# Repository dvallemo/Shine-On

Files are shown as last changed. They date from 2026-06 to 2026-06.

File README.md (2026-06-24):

# Shine On V1

A simple 2-layer LED indicator board designed to plug into a Raspberry Pi 4 GPIO header. Built as a hands-on exercise in schematic capture, PCB layout, component selection, DFM, and hand soldering.

**Designed in:** KiCad  
**Fabricated by:** OSHPark ($5.00 for 3 boards)  
**Components sourced from:** DigiKey  
**Assembly:** Hand soldered by designer  
**Board size:** 25.4 x 25.4 mm (1.00 x 1.00 in), 2-layer

---

## Schematic

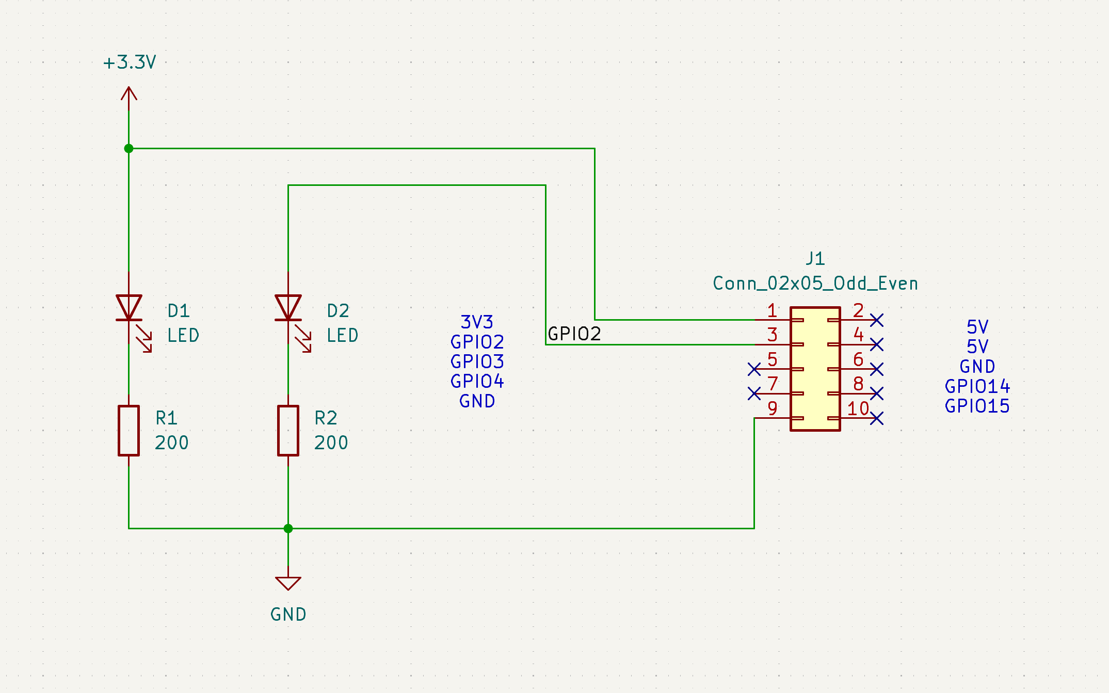
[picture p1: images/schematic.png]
Schematic


Both LEDs are driven in a simple series configuration:

- **D1:** +3.3V -> D1 (LED 1206) -> R1 (200 ohm) -> GND
- **D2:** GPIO2 -> D2 (LED 1206) -> R2 (200 ohm) -> GND

Current limiting resistors R1 and R2 are 200 ohm, 1/4 W rated, 1206 package. At 3.3V with a typical LED forward voltage of ~2.0V:

> I = (3.3V - 2.0V) / 200 ohm = ~6.5 mA

Well within GPIO drive capability (~16 mA max) and LED ratings. Power dissipation per resistor ~8.5 mW, well under the 250 mW rating.

The 10-pin dual-row header (J1) connects directly to the Raspberry Pi 4 GPIO header, exposing +3.3V, GPIO2, and GND.

---

## PCB Layout

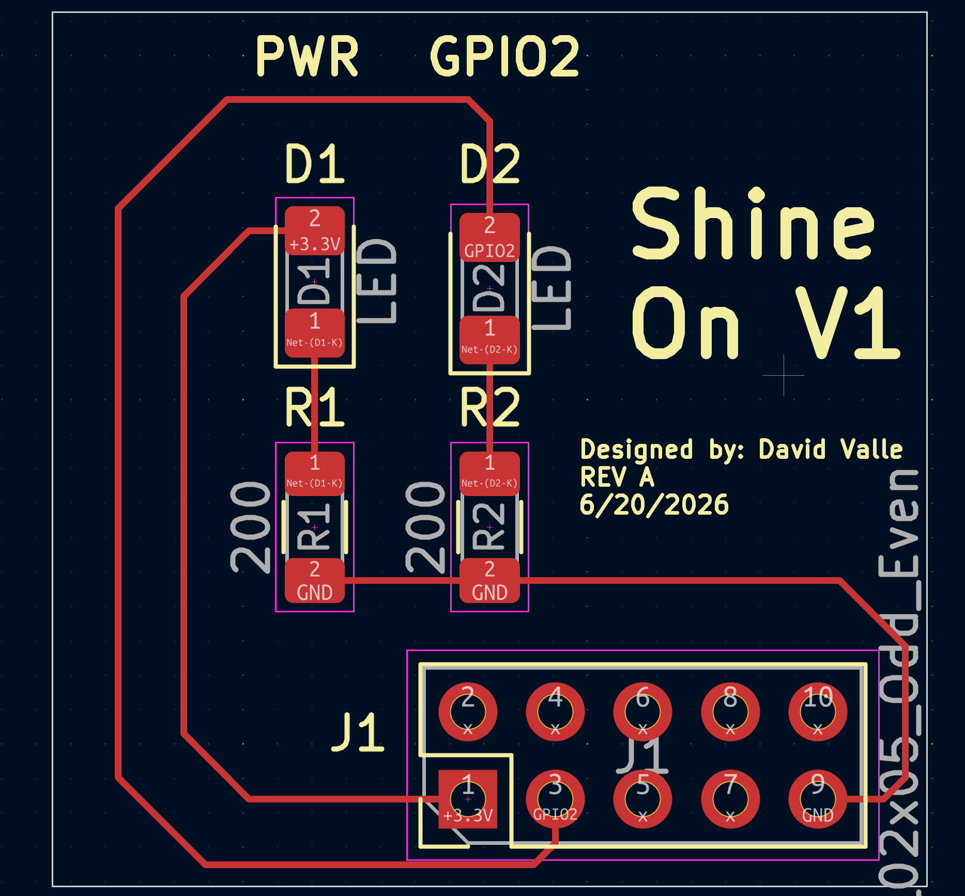
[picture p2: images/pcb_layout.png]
PCB Layout

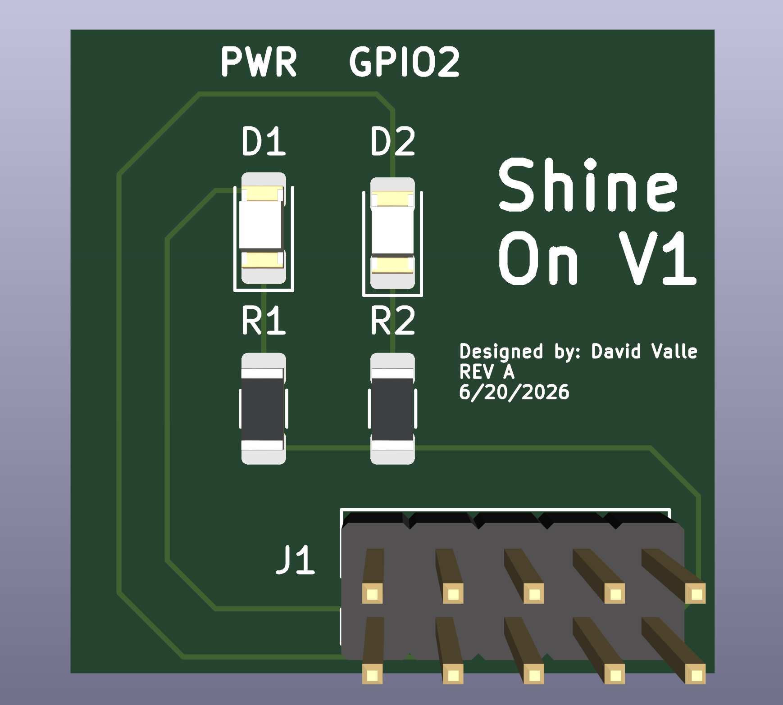
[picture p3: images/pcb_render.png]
PCB Render


### Design Decisions

- **1206 SMD footprints** chosen for all passives and LEDs to enable reliable hand soldering -- larger pads reduce the risk of tombstoning and bridging compared to 0402/0603.
- **No copper pours** -- basic 2-layer board with point-to-point trace routing. Unnecessary complexity avoided for a low-frequency, low-power design.
- **Silkscreen labels** (PWR, GPIO2) placed near each LED for immediate functional identification without referring to a schematic.
- **Board name and revision block** included in silkscreen per professional documentation practice.
- **Chamfered board corners** on the edge cuts layer.

---

## Bill of Materials

| Ref | Description | Part Number | Qty | Unit Price |
|-----|---|---|-----|---|
| R1, R2 | RES 200 ohm 5% 1/4W 1206 | 311-200ERCT-ND (RC1206JR-07200RL) | 50 | $0.027 |
| D1, D2 | Blue LED Surface Mount 1206 | 1568-17734-ND (17734) | 10 | $0.310 |
| J1 | Female Header 2x5 2.54mm Vertical THT | 4324-FHMD-DA010G1NBON-B-ND | 10 | $0.498 |

Components ordered from DigiKey (Order #99956045), shipped 6/22/2026.

**Footprints used:**
- D1, D2: `LED_SMD:LED_1206_3216Metric_Pad1.42`
- R1, R2: `Resistor_SMD:R_1206_3216Metric_Pad1.42`
- J1: `Connector_PinHeader_2.54mm:PinHeader_2x05_P2.54mm_Vertical`

---

## Fabrication

**Fabricator:** [OSHPark](https://oshpark.com)  
**Stack-up:** 2-layer, 1 oz copper, purple solder mask, ENIG finish  
**Board cost:** $5.00 (includes 3 copies)  
**Uploaded:** June 22, 2026

OSHPark renders:

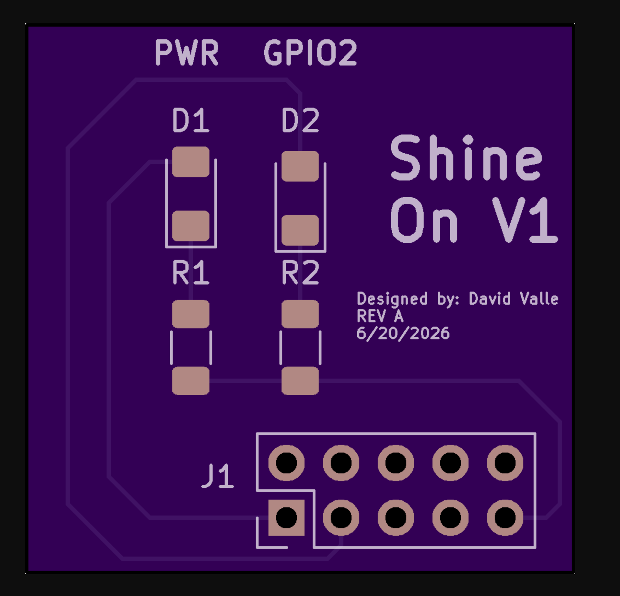
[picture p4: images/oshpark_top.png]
OSHPark Top

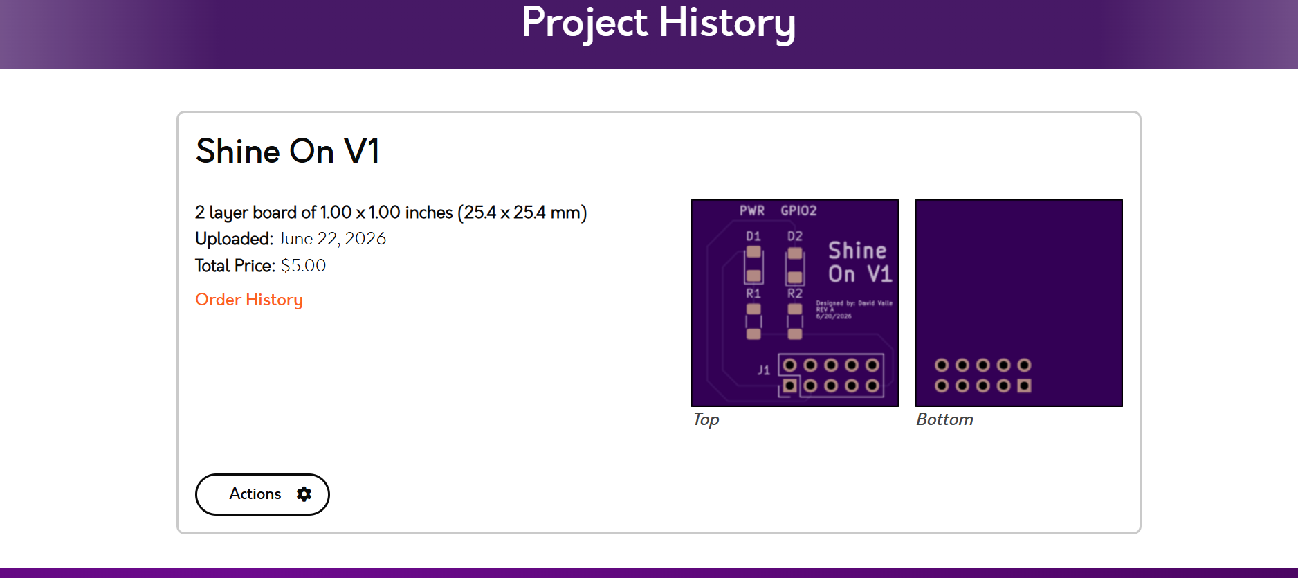
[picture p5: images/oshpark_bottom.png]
OSHPark Bottom


---

## Lessons Learned

- OSHPark's 1" x 1" minimum makes this an ideal low-cost prototype vehicle for simple indicator/breakout boards.
- 1206 is noticeably easier to hand solder than 0603 -- pads are large enough to tin individually and place with tweezers without a hot plate.
- Silkscreen functional labels (not just reference designators) significantly improve board usability without added cost.
- Sourcing resistors in a strip of 50 and LEDs in a strip of 10 keeps unit cost negligible while building personal component inventory.

---

## Repository Structure

```

shine-on-v1/
├── kicad/
├── gerbers/
├── images/
├── bom/
└── README.md
```

---

## Author

**David Valle**  
Electrical Engineering, Stevens Institute of Technology  
REV A -- June 20, 2026

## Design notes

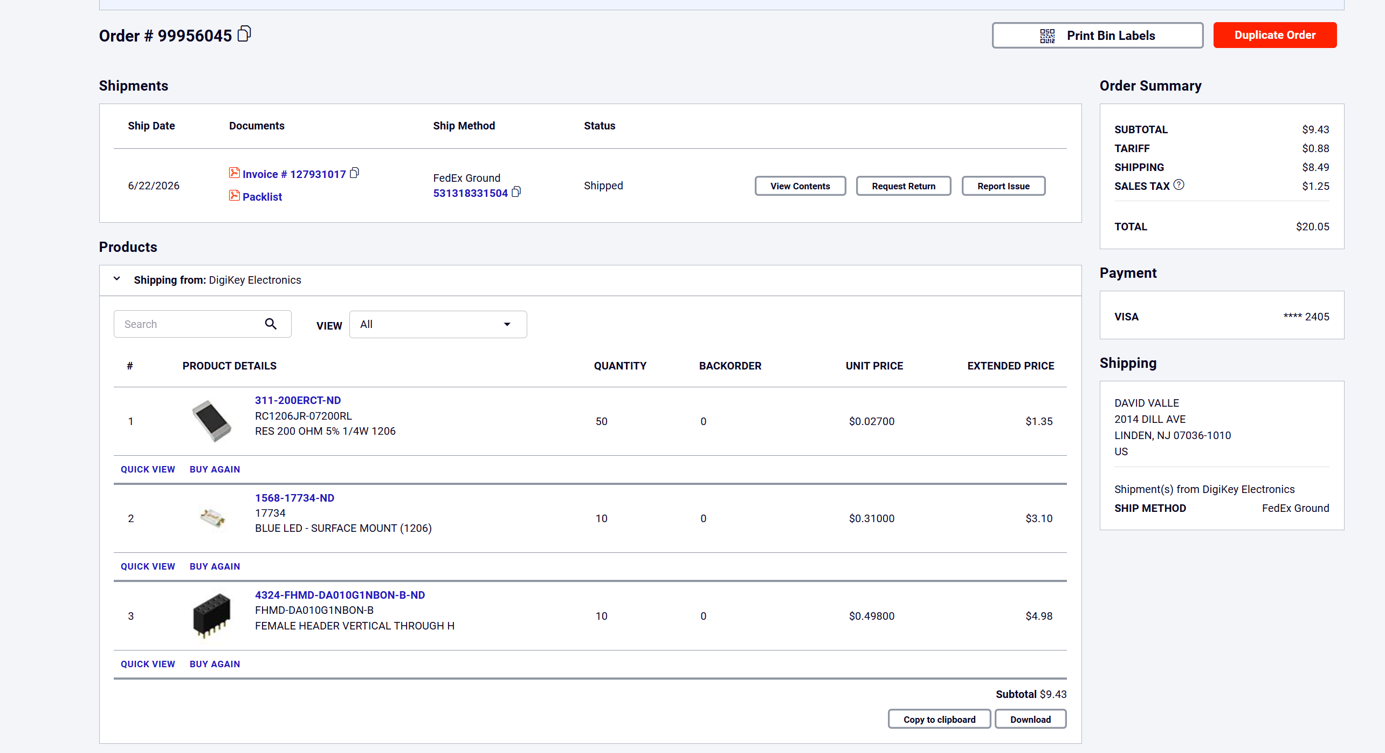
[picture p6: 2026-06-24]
images/Screenshot 2026-06-24 104833.png

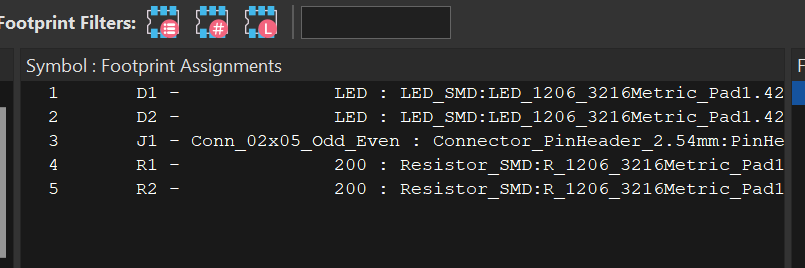
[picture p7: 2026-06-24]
images/Screenshot 2026-06-24 104730.png

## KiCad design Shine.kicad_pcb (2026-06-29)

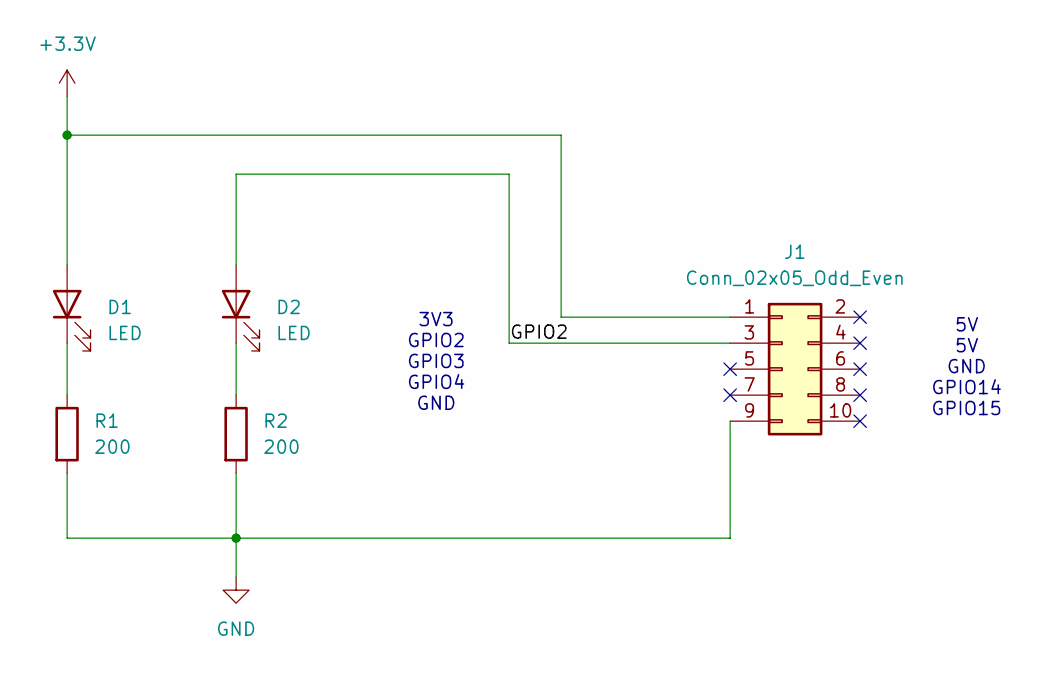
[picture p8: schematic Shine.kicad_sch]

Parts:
D1, D2: LED; LED_1206_3216Metric_Pad1.42x1.75mm_HandSolder
J1: Conn_02x05_Odd_Even; PinHeader_2x05_P2.54mm_Vertical
R1, R2: 200; R_1206_3216Metric_Pad1.30x1.75mm_HandSolder

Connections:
+3.3V: D1.2 (A), J1.1
/GPIO2: D2.2 (A), J1.3
GND: J1.9, R1.2, R2.2
unnamed: D1.1 (K), R1.1
unnamed: D2.1 (K), R2.1

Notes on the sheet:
5V 5V GND GPIO14 GPIO15
3V3 GPIO2 GPIO3 GPIO4 GND

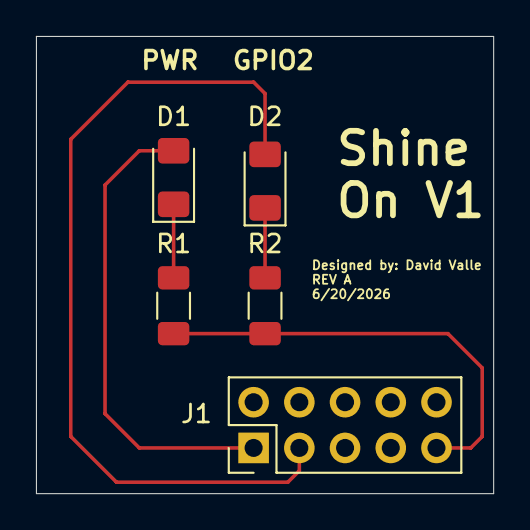
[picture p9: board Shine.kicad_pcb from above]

Board: 2 copper layers, 25.4 x 25.4 mm, 5 parts (0 on the bottom side), 5 nets.
